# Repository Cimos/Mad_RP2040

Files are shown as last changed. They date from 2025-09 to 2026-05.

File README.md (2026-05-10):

# Mad_RP2040

A small RP2040-based keypad PCB. Originally a minimal 2-key board to build confidence with the RP2040 ahead of a full-size keyboard, it has since grown into a 4x4 "anything" keypad with a rotary encoder and per-key RGB.

**Status:** Rev B (4x4) — fabricated November 2025; controller, USB and SK6812MINI-E chain verified, but a matrix wiring error past row 1 / col 1 needs cut-and-bodge to fix on existing units. The fix is not yet in `main`, so fabbing from `main` today reproduces the same bodge. Rev A (2-key) was fabricated and tested; archived under [`resources/rev_a/`](resources/rev_a/).

The encoder footprint is on the board but has not yet been populated/tested.

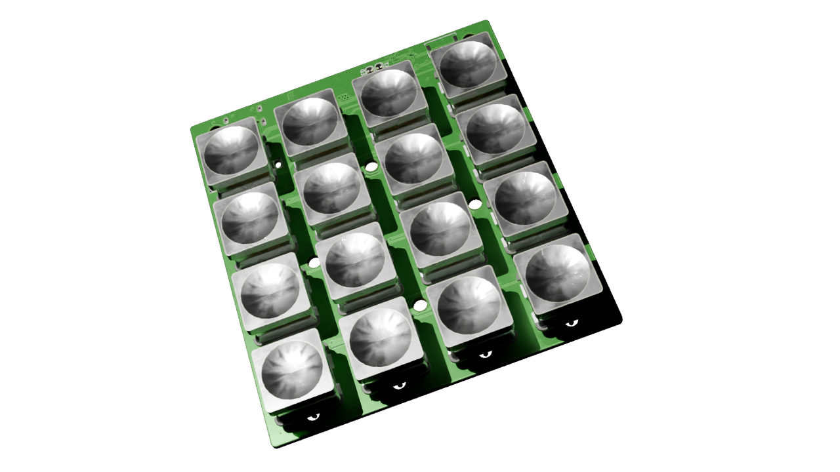
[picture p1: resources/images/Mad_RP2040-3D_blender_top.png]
MadRP2040 top, 3/4 view, with keycaps


## Hardware

- **MCU:** Raspberry Pi RP2040 (QFN-56)
- **Flash:** W25Q128JV (16 MB QSPI)
- **Clock:** 12 MHz ECS-2520MV SMD oscillator
- **Power:** USB-C input, NCP1117-3.3 LDO, ECMF02-2 common-mode filter / ESD protection
- **Switches:** 16x Kailh Choc v2 hotswap (12 mm) in a 4x4 matrix with 1N4148W diodes
- **Encoder:** 1x EC12 rotary encoder with switch
- **Lighting:** Per-key SK6812MINI / SK6812MINI-E RGB LEDs
- **Split support:** TRS interlink (JST-SHL/GH connectors) plus a solder-jumper hand-detect selector
- **Programming:** ARM SWD via Tag-Connect TC2030-NL footprint

Datasheets for the major parts live in [`resources/datasheets/`](resources/datasheets/).

## Repository layout

```
Mad_RP2040.kicad_pro     # KiCad project
Mad_RP2040.kicad_sch     # Top-level schematic
Mad_RP2040.kicad_pcb     # Board layout
Mad_RP2040.kicad_dru     # Design rules
Controller_RP2040.kicad_sch
MCU_RP2040.kicad_sch
Switches.kicad_sch       # Hierarchical sheets
localLib.pretty/         # Project-local footprints
mad_lib/                 # Submodule with shared symbols/footprints
resources/               # Datasheets, enclosure STEP, fabrication outputs
build-panel.yaml         # KiBot panel config (1x2)
options.yaml             # KiBot global options
```

The repo uses a git submodule for `mad_lib`; clone with:

```sh
git clone --recurse-submodules https://github.com/Cimos/Mad_RP2040.git
```

## Build & CI

GitHub Actions in [`.github/workflows/`](.github/workflows/) drive the build via [Cimos/kibot-config](https://github.com/Cimos/kibot-config):

- `build-pcb-action.yaml` — fabrication outputs (gerbers, drills, BOM, position files)
- `build-images-action.yaml` — 2D top/bottom renders
- `build-cad-action.yaml` — STEP / 3D CAD export
- `build-panel-action.yaml` — KiKit panelization (2 cols x 1 row, see `build-panel.yaml`)
- `build-diff-action.yaml` — visual diff against the base branch
- `build-video-action.yaml` — turntable / fly-through video

Each workflow uploads its results as a GitHub Actions artifact on every push.

## Firmware

Keymap and configuration are kept in separate repos:

- [`Cimos/qmk_config`](https://github.com/Cimos/qmk_config) — [QMK](https://qmk.fm/) keymap
- [`Cimos/zmk-config`](https://github.com/Cimos/zmk-config) — [ZMK](https://zmk.dev/) keymap

## Enclosure

FreeCAD-exported cases live in [`resources/enclosures/`](resources/enclosures/):

- `MadRP2040 2-Key Case.step` — Rev A test board
- `MadRP2040 Anything Case.stl` — Rev B 4x4 anything keypad

Released board CAD (STEP) snapshots live under [`resources/rev_a/`](resources/rev_a/).

## Renders

Generated by the `build-images`, `build-cad` and `build-panel` workflows from the latest `main`.

| | |
|---|---|
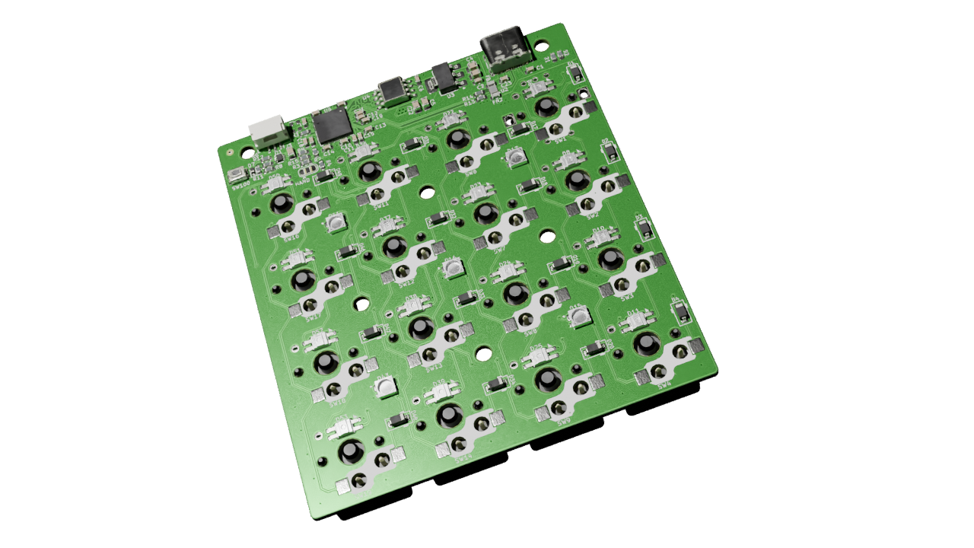
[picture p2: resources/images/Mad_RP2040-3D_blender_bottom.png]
Bottom, 3/4
| Top, 3/4 |  |
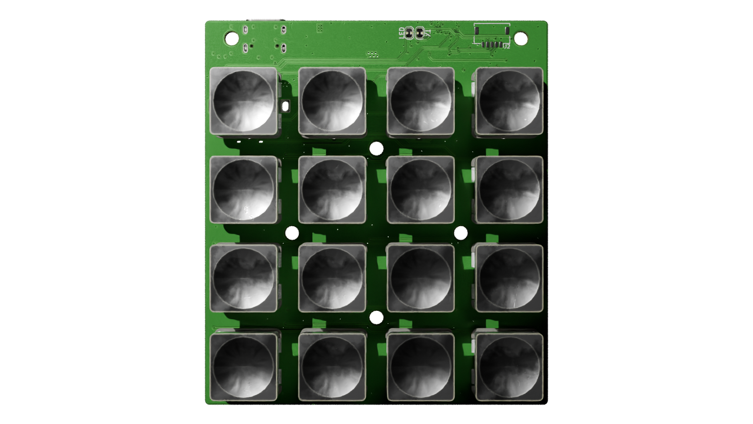
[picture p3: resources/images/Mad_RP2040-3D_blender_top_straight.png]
Top, straight-on
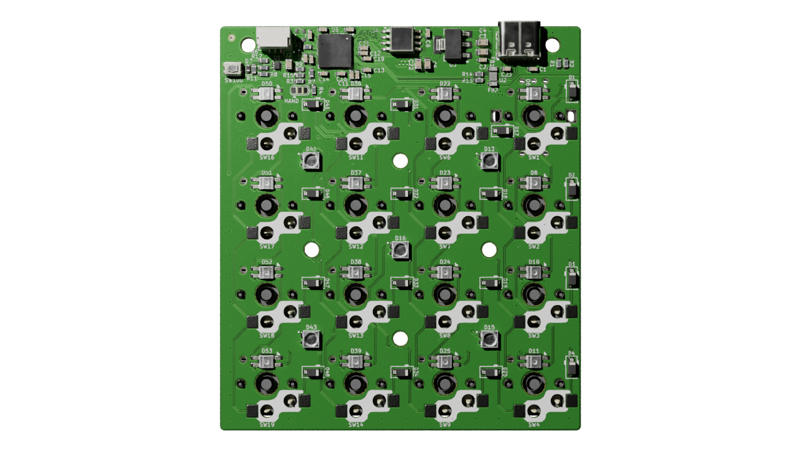
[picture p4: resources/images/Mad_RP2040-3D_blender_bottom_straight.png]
Bottom, straight-on
|  |  |

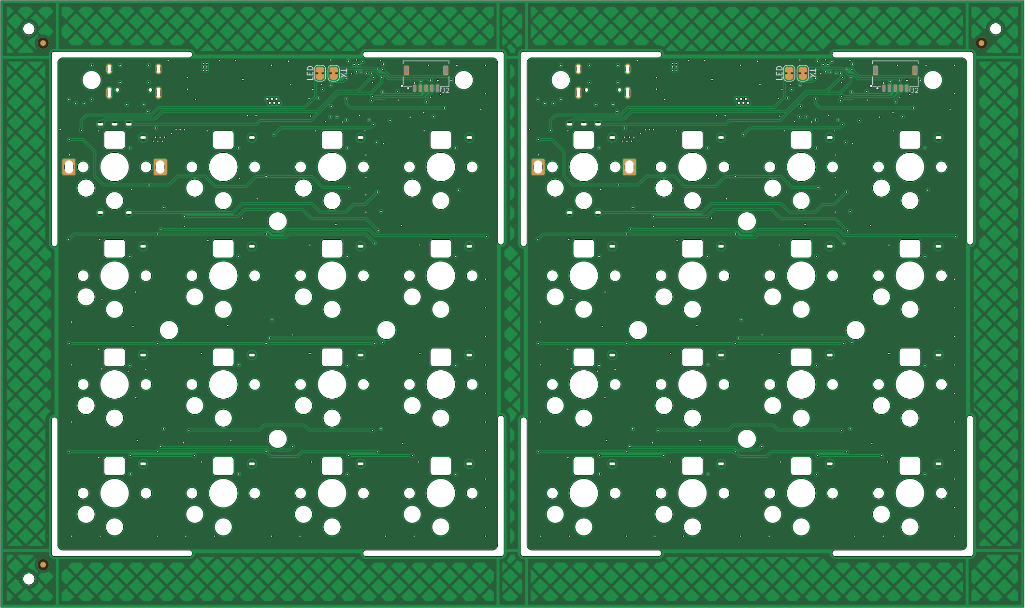
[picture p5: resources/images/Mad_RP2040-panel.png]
1x2 panel


## License

Released under the [MIT License](LICENSE). Copyright (c) 2023 Simon Maddison.

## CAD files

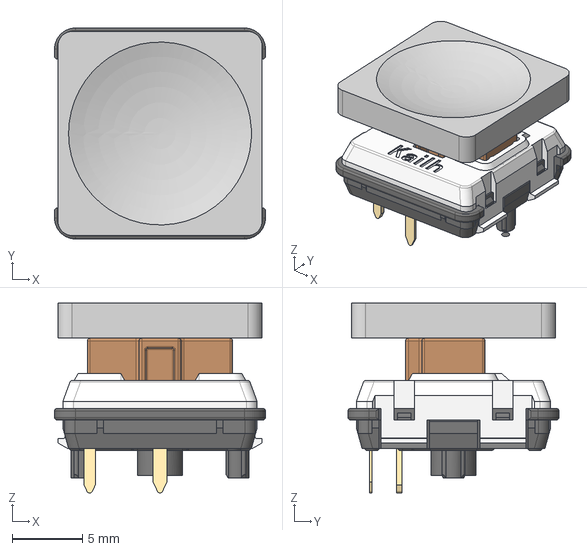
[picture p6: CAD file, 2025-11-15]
3dmodels/minspaced-choc-keycap.step
15.0 x 15.0 x 13.5 mm

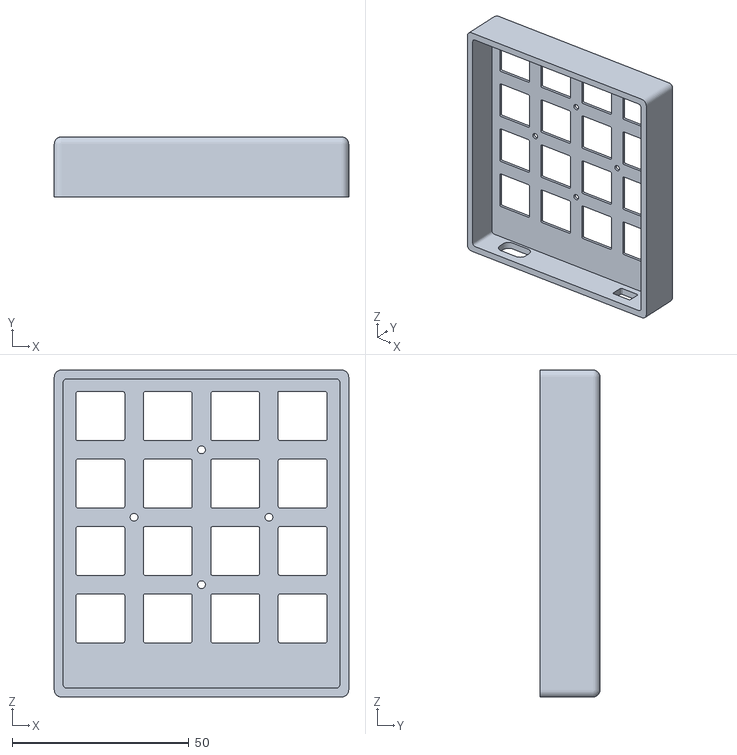
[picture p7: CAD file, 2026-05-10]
resources/enclosures/MadRP2040 Anything Case.stl
83.2 x 17.0 x 92.4

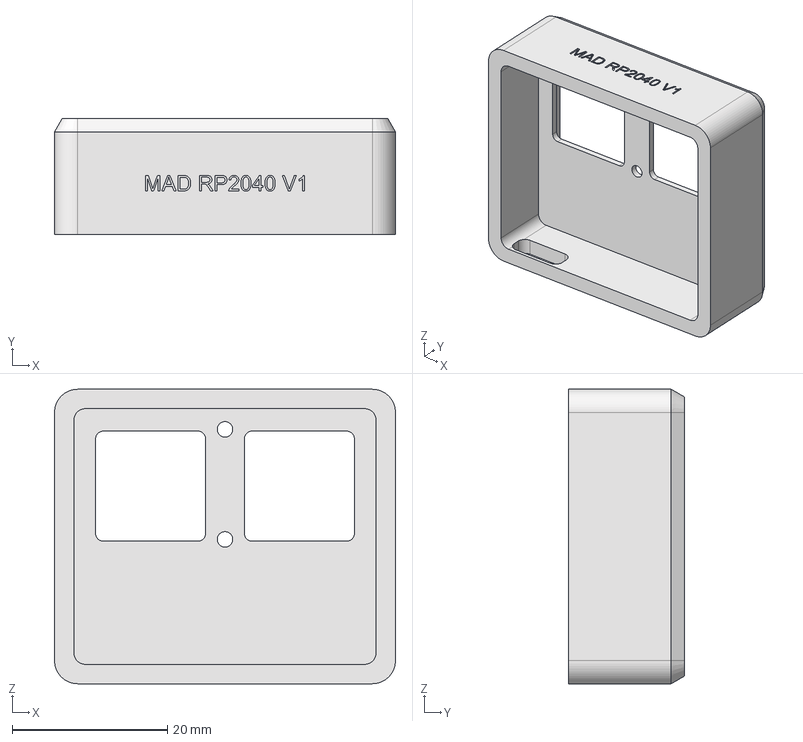
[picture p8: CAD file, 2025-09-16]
resources/enclosures/MadRP2040 2-Key Case.step
44.0 x 15.0 x 38.0 mm

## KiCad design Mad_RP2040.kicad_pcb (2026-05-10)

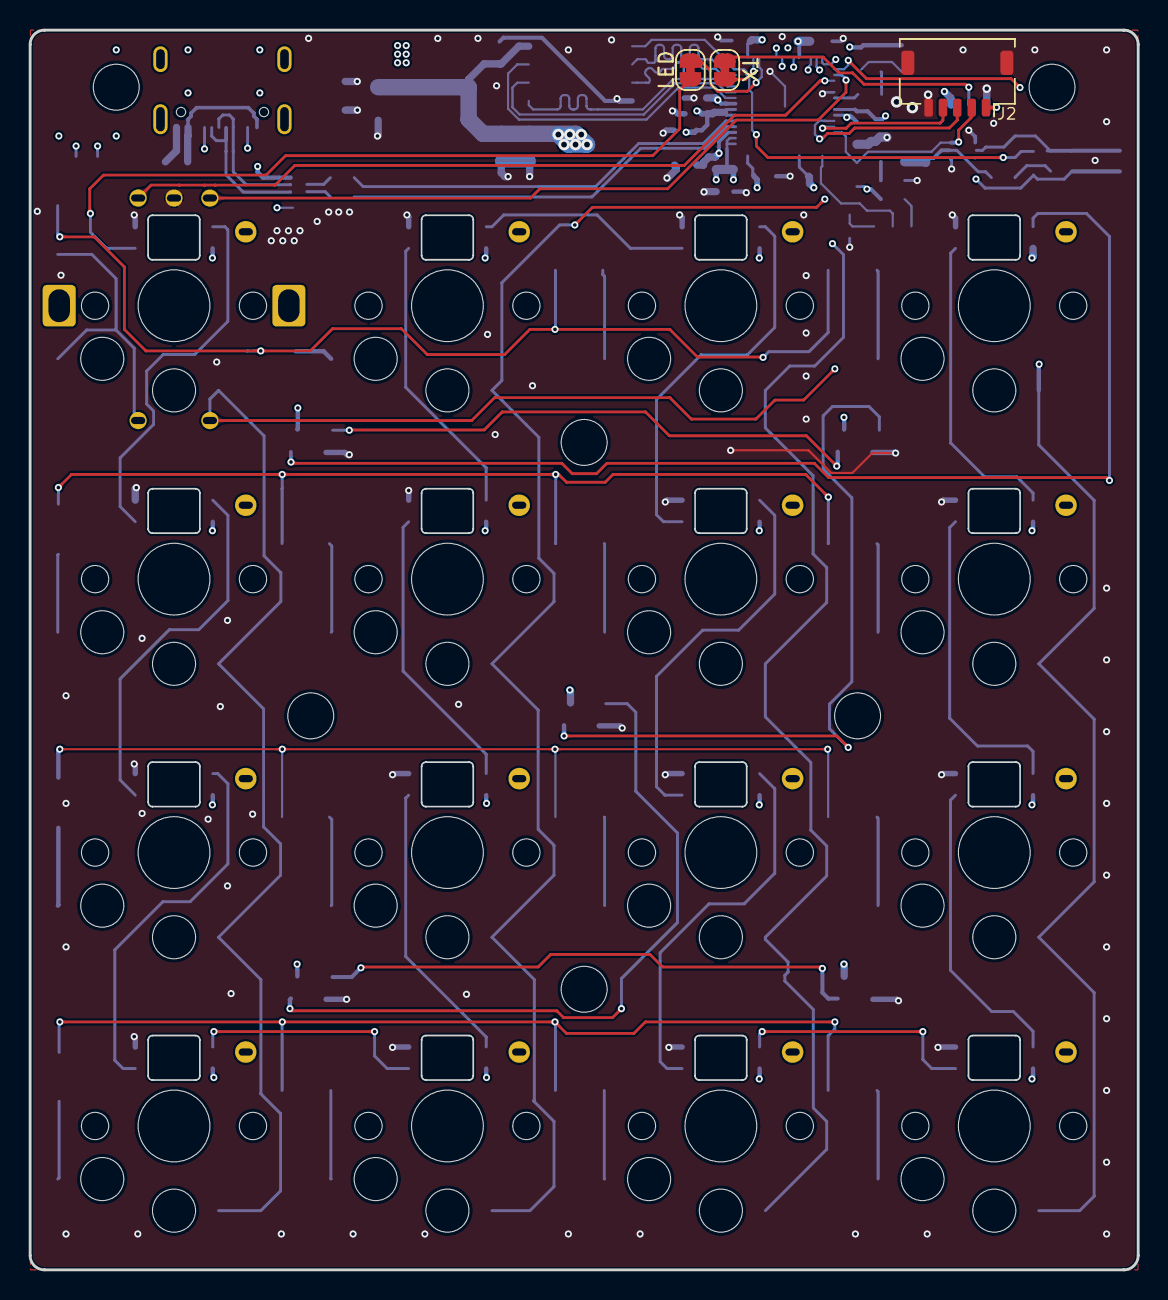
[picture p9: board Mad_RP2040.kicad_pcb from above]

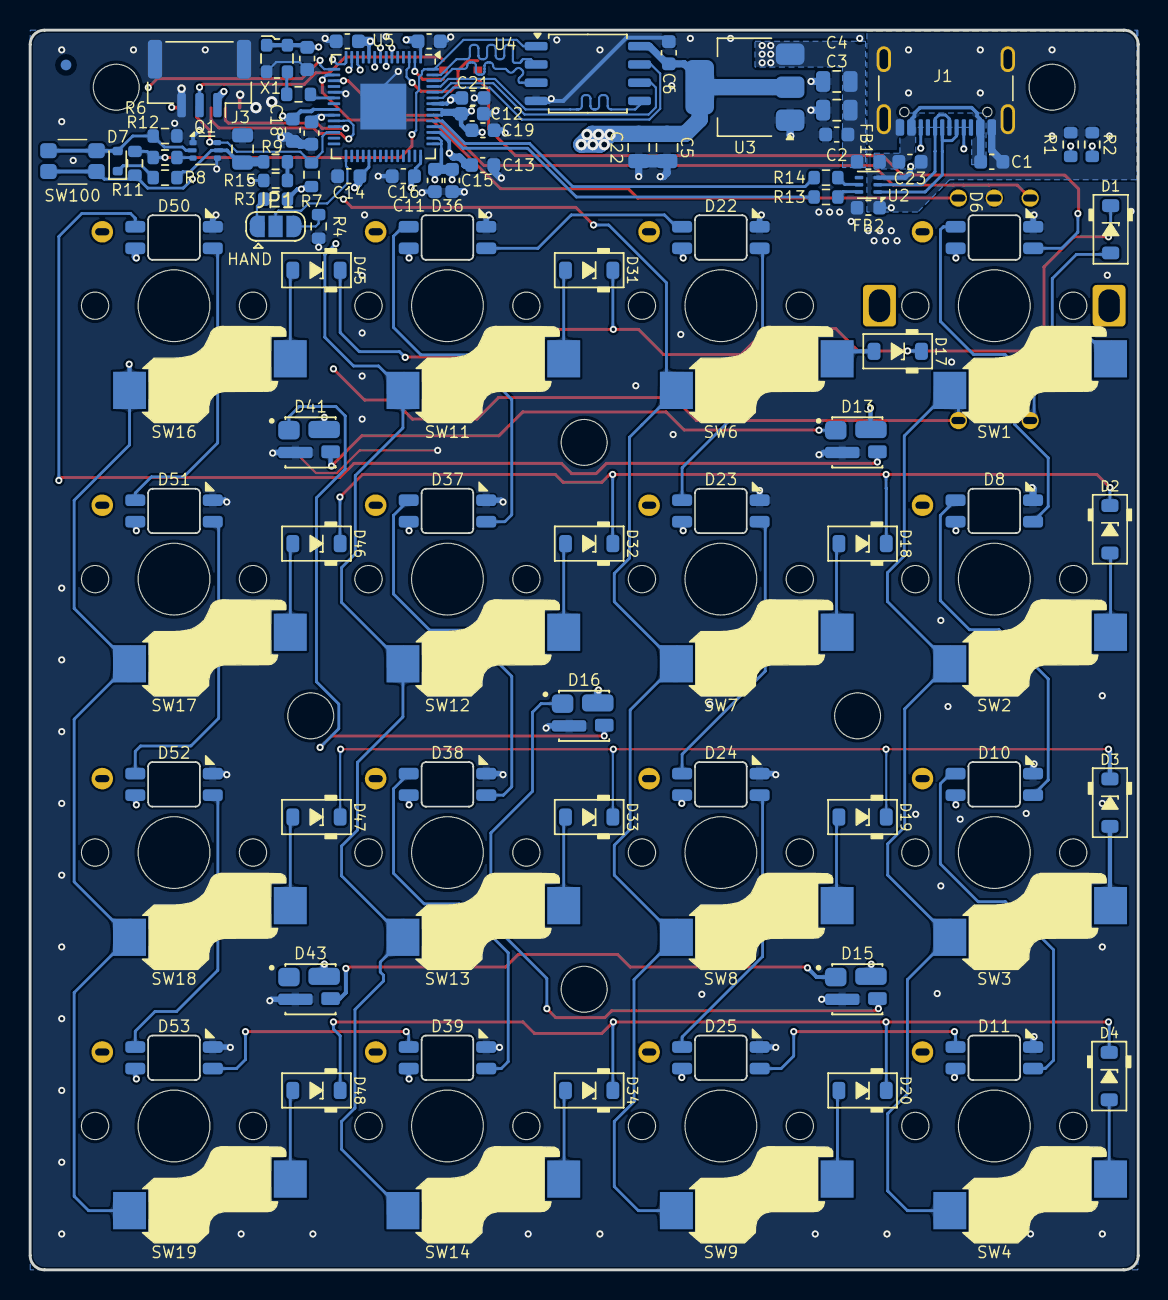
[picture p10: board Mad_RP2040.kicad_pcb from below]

Board: 4 copper layers, 77.2 x 86.4 mm, 117 parts (107 on the bottom side), 83 nets.

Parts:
C1, C2, C6, C7, C10, C11, C12, C14, C16, C17, C18, C19, C20, C21, C23: 100nF; C_0603_1608Metric
C3, C4, C5, C9, C22: 10uF; C_0805_2012Metric
C13, C15: 1uF; C_0603_1608Metric
D1, D2, D3, D4, D17, D18, D19, D20, D31, D32, D33, D34, D45, D46, D47, D48: 1N4148W; D_SOD-123
D6, D8, D10, D11, D22, D23, D24, D25, D36, D37, D38, D39, D50, D51, D52, D53: SK6812_MINI_E; SK6812MINI-E
D7: RB520S30; D_SOD-523
D13, D15, D16, D41, D43: SK6812MINI; SK6812MINI-012
FB1, FB2: BLM18PG330SN1D; L_0603_1608Metric
FID1: Fiducial; Fiducial_0.75mm_Mask1.5mm
H2, H4, H6, H8, H10, H11: MountingHole_Pad; MountingHole_3.2mm_M3
J1: USB_C_Receptacle; USB_C_Receptacle_GCT_USB4105-xx-A_16P_TopMnt_Horizontal
J2: Conn_ARM_SWD_TagConnect_TC2030-NL; JST_SHL_SM05B-SHLS-TF_1x05-1MP_P1.00mm_Horizontal
J3: TRS; JST_GH_SM03B-GHS-TB_1x03-1MP_P1.25mm_Horizontal
JP1: Split Hand Detect Selector; SolderJumper-3_P1.3mm_Open_RoundedPad1.0x1.5mm
JP2, JP3: SolderJumper_2_Bridged; SolderJumper-2_P1.3mm_Bridged_RoundedPad1.0x1.5mm
Q1: 2N7002PV,115; SOT-666
R1, R2, R3, R4: 5K1; R_0603_1608Metric
R6, R7, R11: 10K; R_0603_1608Metric
R8, R9, R15: 51K; R_0603_1608Metric
R10, R12: 1K; R_0603_1608Metric
R13, R14: 27R; R_0603_1608Metric
SW1: RotaryEncoder_Switch; keyswitch_choc12_hotswap_1u_rotary_encoder_ec12
SW2, SW3, SW4, SW6, SW7, SW8, SW9, SW11, SW12, SW13, SW14, SW16, SW17, SW18, SW19: SW_SPST; keyswitch_choc12_hotswap_1u
SW100: EVPAA202K; EVP-AA202K
T1, T2, T3, T4: Tab
U0: PCB; BOM
U2: ECMF02-2AMX6; ST_UQFN-6L_1.5x1.7mm_P0.5mm
U3: NCP1117-3.3; SOT-223-3_TabPin2
U4: W25Q128JVSIQ; SOIC-8_5.23x5.23mm_P1.27mm
U5: RP2040; QFN-56-1EP_7x7mm_P0.4mm_EP3.2x3.2mm
X1: ECS-2520MVLC-120-CN; Oscillator_SMD_ECS_2520MV-xxx-xx-4Pin_2.5x2.0mm

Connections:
+5V: C2.1, C3.1, C4.1, D6.1 (VDD), D8.1 (VDD), D10.1 (VDD), D11.1 (VDD), D13.2 (VDD), D15.2 (VDD), D16.2 (VDD), D22.1 (VDD), D23.1 (VDD), D24.1 (VDD), D25.1 (VDD), D36.1 (VDD), D37.1 (VDD), D38.1 (VDD), D39.1 (VDD), D41.2 (VDD), D43.2 (VDD), D50.1 (VDD), D51.1 (VDD), D52.1 (VDD), D53.1 (VDD), FB1.2, J3.1, U3.3 (VI)
/Col0: SW1.S2, SW2.2 (B), SW3.2 (B), SW4.2 (B), U5.12 (GPIO9)
/Col1: SW6.2 (B), SW7.2 (B), SW8.2 (B), SW9.2 (B), U5.13 (GPIO10)
/Col2: SW11.2 (B), SW12.2 (B), SW13.2 (B), SW14.2 (B), U5.14 (GPIO11)
/Col3: SW16.2 (B), SW17.2 (B), SW18.2 (B), SW19.2 (B), U5.15 (GPIO12)
/LED: D6.4 (DIN), JP3.2 (B)
/PreFIlterGND: C1.2, C23.2, FB2.1, J1.A1 (GND), J1.A12 (GND), J1.B1 (GND), J1.B12 (GND), J1.S1 (SHIELD), R1.2, R2.2, U2.3 (GND)
/PreFilter_USB_D+: J1.A6 (D+), J1.B6 (D+), U2.2 (D-_in)
/PreFilter_USB_D-: J1.A7 (D-), J1.B7 (D-), U2.1 (D+_in)
/REA: SW1.A, U5.16 (GPIO13)
/REB: SW1.B, U5.17 (GPIO14)
/RP2040/3V3: C5.1, C6.1, C7.1, C10.1, C11.1, C12.1, C14.1, C15.2, C16.1, C17.1, C18.1, C19.1, C22.1, J2.1, R3.1, R7.2, R11.2, SW100.1, U3.2 (VO), U4.8 (VCC), U5.1 (IOVDD), U5.10 (IOVDD), U5.22 (IOVDD), U5.33 (IOVDD), U5.42 (IOVDD), U5.43 (ADC_AVDD), U5.44 (VREG_VIN), U5.48 (USB_VDD), U5.49 (IOVDD), X1.1 (Tri-State), X1.4 (VDD)
/RP2040/LED: JP3.1 (A), U5.3 (GPIO1)
/RP2040/RP2040/1V1: C13.2, C20.1, C21.1, U5.23 (DVDD), U5.45 (VREG_VOUT), U5.50 (DVDD)
/RP2040/RP2040/GPIO18: JP1.2 (C), U5.29 (GPIO18)
/RP2040/RP2040/QSPI_SCLK: U4.6 (CLK), U5.52 (QSPI_SCLK)
/RP2040/RP2040/QSPI_SD0: U4.5 (DI(IO0)), U5.53 (QSPI_SD0)
/RP2040/RP2040/QSPI_SD1: U4.2 (DO(IO1)), U5.55 (QSPI_SD1)
/RP2040/RP2040/QSPI_SD2: U4.3 (IO2), U5.54 (QSPI_SD2)
/RP2040/RP2040/QSPI_SD3: U4.7 (IO3), U5.51 (QSPI_SD3)
/RP2040/RP2040/QSPI_~CS: R11.1, R12.2, U4.1 (~CS), U5.56 (QSPI_SS_N)
/RP2040/RP2040/USB_D+: R14.2, U5.47 (D+)
/RP2040/RP2040/USB_D-: R13.2, U5.46 (D-)
/RP2040/RP2040/XTAL_IN: R10.1, U5.20 (XTAL_IN)
/RP2040/SWCLK: J2.3, U5.24 (SWCLK)
/RP2040/SWDIO: J2.4, U5.25 (SWDIO)
/RP2040/TX: JP2.1 (A), U5.2 (GPIO0)
/RP2040/USB_D+: R14.1, U2.5 (D-_out)
/RP2040/USB_D-: R13.1, U2.6 (D+_out)
/RP2040/~RST: J2.2, Q1.6 (D), R7.1, U5.26 (~RUN)
/Row0: D1.1 (K), D17.1 (K), D31.1 (K), D45.1 (K), U5.6 (GPIO4)
/Row1: D2.1 (K), D18.1 (K), D32.1 (K), D46.1 (K), U5.7 (GPIO5)
/Row2: D3.1 (K), D19.1 (K), D33.1 (K), D47.1 (K), U5.8 (GPIO6)
/Row3: D4.1 (K), D20.1 (K), D34.1 (K), D48.1 (K), U5.9 (GPIO7)
/TX: J3.2, JP2.2 (B)
GND: C2.2, C3.2, C4.2, C5.2, C6.2, C7.2, C9.2, C10.2, C11.2, C12.2, C13.1, C14.2, C15.1, C16.2, C17.2, C18.2, C19.2, C20.2, C21.2, C22.2, D6.3 (GND), D8.3 (GND), D10.3 (GND), D11.3 (GND), D13.4 (GND), D15.4 (GND), D16.4 (GND), D22.3 (GND), D23.3 (GND), D24.3 (GND), D25.3 (GND), D36.3 (GND), D37.3 (GND), D38.3 (GND), D39.3 (GND), D41.4 (GND), D43.4 (GND), D50.3 (GND), D51.3 (GND), D52.3 (GND), D53.3 (GND), FB2.2, J2.5, J2.MP (MountPin), J3.3, J3.MP (MountPin), Q1.1 (S), Q1.4 (S), R4.2, R6.1, R15.2, SW1.C, U3.1 (GND), U4.4 (GND), U5.19 (TESTEN), U5.57 (GND), X1.2 (GND)
unnamed: D1.2 (A), SW1.S1
unnamed: D2.2 (A), SW2.1 (A)
unnamed: D3.2 (A), SW3.1 (A)
unnamed: D4.2 (A), SW4.1 (A)
unnamed: D6.2 (DOUT), D8.4 (DIN)
unnamed: D7.2 (A), Q1.2 (G), R6.2, SW100.2
unnamed: D7.1 (K), R8.2
unnamed: D8.2 (DOUT), D10.4 (DIN)
unnamed: D10.2 (DOUT), D11.4 (DIN)
unnamed: D11.2 (DOUT), D25.4 (DIN)
unnamed: D13.1 (DIN), D50.2 (DOUT)
unnamed: D13.3 (DOUT), D41.1 (DIN)
unnamed: D15.1 (DIN), D16.3 (DOUT)
unnamed: D15.3 (DOUT), D43.1 (DIN)
unnamed: D16.1 (DIN), D41.3 (DOUT)
unnamed: D17.2 (A), SW6.1 (A)
unnamed: D18.2 (A), SW7.1 (A)
unnamed: D19.2 (A), SW8.1 (A)
unnamed: D20.2 (A), SW9.1 (A)
unnamed: D22.4 (DIN), D23.2 (DOUT)
unnamed: D22.2 (DOUT), D36.4 (DIN)
unnamed: D23.4 (DIN), D24.2 (DOUT)
unnamed: D24.4 (DIN), D25.2 (DOUT)
unnamed: D31.2 (A), SW11.1 (A)
unnamed: D32.2 (A), SW12.1 (A)
unnamed: D33.2 (A), SW13.1 (A)
unnamed: D34.2 (A), SW14.1 (A)
unnamed: D36.2 (DOUT), D37.4 (DIN)
unnamed: D37.2 (DOUT), D38.4 (DIN)
unnamed: D38.2 (DOUT), D39.4 (DIN)
unnamed: D39.2 (DOUT), D53.4 (DIN)
unnamed: D45.2 (A), SW16.1 (A)
unnamed: D46.2 (A), SW17.1 (A)
unnamed: D47.2 (A), SW18.1 (A)
unnamed: D48.2 (A), SW19.1 (A)
unnamed: D50.4 (DIN), D51.2 (DOUT)
unnamed: D51.4 (DIN), D52.2 (DOUT)
unnamed: D52.4 (DIN), D53.2 (DOUT)
unnamed: J1.A5 (CC1), R1.1
unnamed: J1.B5 (CC2), R2.1
unnamed: JP1.1 (A), R3.2
unnamed: JP1.3 (B), R4.1
unnamed: Q1.3 (D), R12.1
unnamed: C9.1, Q1.5 (G), R8.1, R9.1
unnamed: R9.2, R15.1
unnamed: R10.2, X1.3 (OUT)
VBUS: C1.1, C23.1, FB1.1, J1.A4 (VBUS), J1.A9 (VBUS), J1.B4 (VBUS), J1.B9 (VBUS)

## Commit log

2024-08-06 Move RP2040 controller into local
    [Controller_RP2040.kicad_sch, MCU_RP2040.kicad_sch, Mad_RP2040.kicad_pcb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]
2024-08-06 Annotation update
    [Controller_RP2040.kicad_sch, MCU_RP2040.kicad_sch, Mad_RP2040.kicad_sch]
2024-08-06 Board update
    [MCU_RP2040.kicad_sch, Mad_RP2040.kicad_pcb]
2024-08-06 remove crumbcatcher name from files
    [Mad_RP2040.kicad_sch, Switches.kicad_sch]
2024-08-07 Update github actions
    Remove double up on actions
    Remove kibot config file to what the action is looking for
    Update date on title block
    Update github actions
    update github action
    update schematic
    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
    [Controller_RP2040.kicad_sch, Mad_RP2040.kicad_pcb, Mad_RP2040.kicad_sch]
2024-08-07 Finish off part placement
    [Controller_RP2040.kicad_sch, Mad_RP2040.kicad_pcb]
2024-08-07 Add todo
    [Mad_RP2040.kicad_sch]
2024-08-08 Cleanup bom, remove spaces and lcsc fields
    [Controller_RP2040.kicad_sch, MCU_RP2040.kicad_sch, Mad_RP2040.kicad_sch]
2024-08-08 Update Models, Finalize LED selections, add backlight, ...
    add mounting holes, add fids, cleanup
    [Controller_RP2040.kicad_sch, MCU_RP2040.kicad_sch, Mad_RP2040.kicad_pcb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]
2024-08-09 BOM update, add lcsc pn to componenets.
    [Controller_RP2040.kicad_sch, MCU_RP2040.kicad_sch, Mad_RP2040.kicad_pcb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]
2024-08-10 BOM update
    [Controller_RP2040.kicad_sch, MCU_RP2040.kicad_sch, Mad_RP2040.kicad_pcb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]
2024-08-10 BOM consolidation
    [Controller_RP2040.kicad_sch, MCU_RP2040.kicad_sch, Mad_RP2040.kicad_pcb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]
2024-08-11 Update design rules
    [Mad_RP2040.kicad_pcb]
2024-08-11 Add dru, start routing
    [MCU_RP2040.kicad_sch, Mad_RP2040.kicad_pcb]
2024-08-11 Fix some errors, more routing
    [Mad_RP2040.kicad_pcb]
2024-08-11 Update todo's
    [Mad_RP2040.kicad_pcb, Mad_RP2040.kicad_sch]
2024-08-13 Finish off routing
    [Controller_RP2040.kicad_sch, MCU_RP2040.kicad_sch, Mad_RP2040.kicad_pcb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]
2024-08-15 Minor silk update
    [MCU_RP2040.kicad_sch, Mad_RP2040.kicad_pcb, Mad_RP2040.kicad_sch]
2025-04-05 1 Add Panel (#2)
    * #1 Add panel file and updated github action
    * #1 Test for if panel file exhists
    * #1 Rejig github actions
    * Update job descriptions
    * Add board tabs
    * adjust panel array
    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
    [MCU_RP2040.kicad_sch, Mad_RP2040.kicad_pcb, Mad_RP2040.kicad_sch]
2025-09-16 Larger 4x4 Anything Keypad (#3)
    * Update usb data pins, update to fix 3v3 reg not adj
    * Remove Xtal test pad, update PCB
    * Update footprint on back light SK6812MINI LED, add more back lights.
    * Update PCB back light
    * Expand board to 4x5, update rev to b
    * Update github workflow
    * Rough placement of components. Remove one layer of keys (4x4 -> 4x3)
    * More placement, start routing, fix up some schematic connections
    * Update tabs
    * Update github actions to use main not master for kibot-config checkout
    * Review Schematic, Add TRS connector. Continue routing
    * Continue routing.
    * Finish off routing, clear DRC/ERC's, add missing datasheets
    * Update panel size, fix kikit tab link, adj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
    [Controller_RP2040.kicad_sch, MCU_RP2040.kicad_sch, MadRP2040 Case v44.step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]
2025-11-15 Minor updates after building and testing boards. Added key caps to model
    [Controller_RP2040.kicad_sch, MCU_RP2040.kicad_sch, Mad_RP2040.kicad_pcb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]
2026-04-21 Update date
    [Controller_RP2040.kicad_sch, MCU_RP2040.kicad_sch, Mad_RP2040.kicad_pcb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]
2026-05-10 Expand README (#4)
    * Expand README with hardware, build, and enclosure details
    Replaces the one-line description with a standard project README:
    overview, hardware summary, repo layout, CI workflow rundown,
    enclosure pointer, and license. Includes a TODO placeholder for a
    PCB render URL once the build-images artifact is published.
    https://claude.ai/code/session_011Mt2xiQHKvSeekri8G1S4w
    * Add firmware section to README
    * Note rev A status in README
    * Add Rev B render gallery, encoder note, ZMK config link, anything case
    - Replace TODO PCB-render placeholder with top 3/4 hero
    - Add Renders section: top/bottom 3/4 + straight, 1x2 panel
    - Update Status to Rev B with matrix-bug caveat
    - Not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
    [MadRP2040 2-Key Case.step, MadRP2040 Anything Case.stl]
2026-05-10 Move keycap STEP out of footprint lib (#6)
    [Mad_RP2040.kicad_pcb, minspaced-choc-keycap.step]
2026-06-16 ci: publish build artifacts to GitHub Release on version tags (#11)
    Add release.yaml workflow triggered on `v*` tags. Rebuilds the PCB
    datapack, 3D model, 2D images, and panel datapack (when build-panel.yaml
    is present) from the tagged commit via the Cimos/kibot-config action,
    zips each into a versioned archive, and publishes a GitHub Release with
    auto-generated notes and the archives attached.
2026-06-16 ci: consolidate build workflows + hygiene (concurrency, paths, perms, pinning) (#13)
    * ci: consolidate build workflows + hygiene (concurrency, paths, perms, pin)
    - Consolidate build-pcb/cad/images into one matrix workflow (build-datapacks.yaml)
    with panel as a second job; delete the 4 superseded files.
    - Add concurrency cancel-in-progress to CI workflows (serialize, no waste).
    - Add path filters so doc/CI-only commits don't trigger board builds.
    - Trim triggers: build on PRs + main (was every branch push); diff is PR-only.
    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
2026-06-16 ci: warn-only ERC/DRC design-review gate with PR comment (#14)
    * ci: add warn-only ERC/DRC design-review gate with PR comment
    New design-review.yaml runs KiCad ERC + DRC on PRs (re-enabling the checks
    that the shared kibot-config options.yaml disables, via a project-local
    design-review.kibot.yaml). DRC uses the custom Mad_RP2040.kicad_dru. The
    gate is warn-only (continue-on-error) and posts/updates a single summary
    comment on the PR via the gh CLI (no third-party actions). Reports are
    uploaded as an artifact. Comment posting is guarded to same-repo PRs
    (fork PR tokens are read-only).
    * ci: harden design-review gate — split jobs, parsed ERC/DRC summary
    Security: split into two jobs so t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
2026-06-16 ci: kicad-happy AI design review (fork-safe, SHA-pinned, no AI/egress) (#15)
    * ci: add kicad-happy AI design-review (fork-safe, SHA-pinned, no AI/egress)
    Adds the deterministic tier of aklofas/kicad-happy as a PR design review,
    following the security audit's required mitigations:
    - Fork-safe two-workflow pattern: analysis runs on pull_request with a
    read-only token; comment posts via workflow_run with pull-requests:write
    and runs no third-party analysis code.
    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
2026-06-16 ci: stitch video frames into MP4; add CLAUDE.md project/CI guide (#17)
    - build-video-action.yaml: add a non-fatal ffmpeg step that renumbers the
    rendered PNG frames and assembles output_video/<project>-3d.mp4 (padded to
    even dims, yuv420p). Resolves the long-standing TODO. First real run is on
    the next push to main (push-only trigger; couldn't be CI-tested on a PR).
    - CLAUDE.md: document the CI/CD architecture, release process, action-pinning
    policy, the two design-review gates, kicad-happy security invariants, and
    known issues (unvendored kbd footprint lib, missing I2C pull-ups, MP4 step
    pending first main run).
2026-06-22 ci: make release workflow idempotent and dispatchable for any tag (#18)
    The publish step used 'gh release create', which fails if the release already
    exists — that's what errored the first v0.0.1 run after the build succeeded.
    Make it create-or-update: upload assets with --clobber when the release exists,
    create it otherwise.
    Add workflow_dispatch with a 'tag' input so a release can be built for any
    existing tag, including older tags whose commit predates this workflow (the
    workflow runs from the default branch, the board is checked out from the tag).
    The dispatch input is passed via env and validated against v[0-9]* so it can't
    be expanded as shell.
2026-10-10 Vendor Kailh choc socket STEP model and repoint footprints (#19) (#20)
2026-10-10 Add DRC rule for minimum plated slot width (#7)
    Enforces JLCPCB's 0.5mm minimum plated slot width. The condition
    matches plated through-hole pads whose X and Y hole dimensions
    differ (i.e. slots), and constrains the smaller dimension via the
    hole_size minimum.
2026-10-10 Add DRC rule for hole-to-board-edge clearance (#9)
    Enforces JLCPCB's 1mm minimum distance between drilled holes (PTH,
    NPTH, vias) and the board edge. Castellated pads are excluded
    since they intentionally sit on the edge. The minimum board size
    note (10x10mm) is left as documentation since it cannot be
    expressed as a DRC constraint.
2026-10-10 Add DRC rule for minimum non-plated slot width (#8)
    * Expand README (#4)
    - Add Renders section: top/bottom 3/4 + straight, 1x2 pane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
